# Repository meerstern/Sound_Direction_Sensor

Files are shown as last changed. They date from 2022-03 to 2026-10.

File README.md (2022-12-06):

#  音方位センサ基板
# Sound_Direction_Sensor
This board detects the direction of sound with 4-pdm mems mic using GCC-PHAT algorithm.

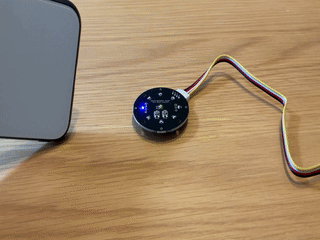
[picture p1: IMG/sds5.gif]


## 概要
  * 音の時間差から計算して8つのLED及びI2C、UARTで結果(角度)を出力する基板です  
  * 4つのPDMデジタルマイクSPH0641LMおよびSTM32F411RCを搭載しています  
  * GCC-PHAT(Generalized Cross-Correlation. PHAse Transform)方式です  
  * 数kHz前後の音をフィルタして音の時間差から方位を検出します  
  * 誤検知を低減するために、音変化（標準偏差）が大きい場合に角度出力します  
  * 音変化（標準偏差）の閾値は基板上の可変抵抗もしくはコマンドから変更できます  
  * 人の声やリズム音等の方位検出に向いています  
  * 手やモノを叩く音等の瞬間的な音の場合、反射等の影響が大きく誤検知しやすくなります  
  
## 仕様
  * 角度分解能は約22.5度～30度程度(音源や環境、処理に依存)
  * 方位LED 8つ搭載
  * 1秒間に約5~6回測定し、結果を出力します  
  * 36kHzサンプリング
  * 電源3.3~5V、UARTもしくはI2C(5V耐圧)
  * I2CはGrove互換コネクタ搭載、UARTは基板上ピンヘッダから接続  
  * UARTボーレート9600bps、データサイズ8bit、パリティ無、ストップ1bitが既定値です  
  * 起動直後にのみ基板上の可変抵抗を読み取り、音変化（標準偏差）の閾値として設定します  
  * I2CもしくはUARTから音変化（標準偏差）閾値を上書き設定できます  
  * リセットや電源再投入で音変化（標準偏差）閾値は消去され、保持されません(可変抵抗値が再度反映)  
  * 電源投入後、自動的に方位検知を開始するため、電源供給のみで方位検知可能です  
  
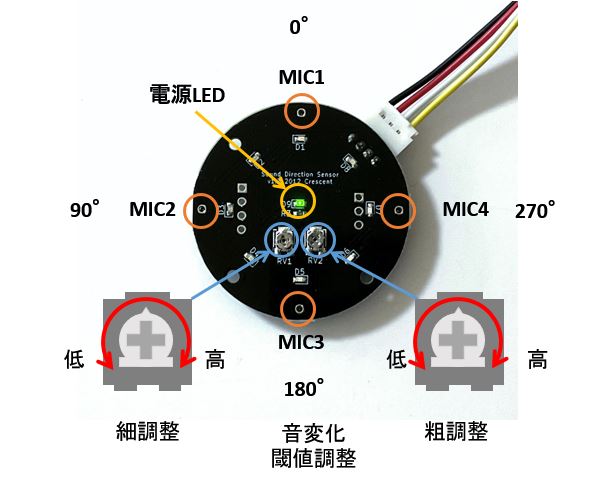
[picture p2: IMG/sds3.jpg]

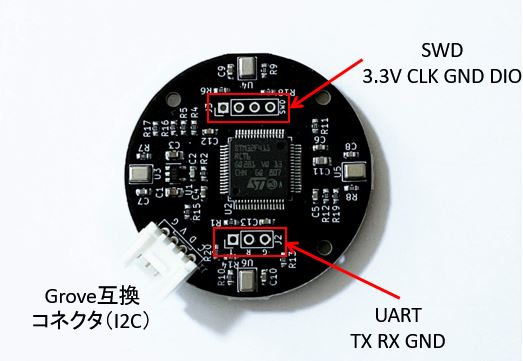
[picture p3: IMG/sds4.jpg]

  
## 外形
  * 40mm円形基板(コネクタ含まず)
  * マイク距離36mm円形
  * M2穴x3 穴間隔横および縦 24.3mm
  
## アプリケーション例
  * 音源の方向を向く小型の首振りロボット  
  * 声でカメラの向きを動かして撮影するカメラステージ
   
## 注意点
  * 厳密な角度検出が必要な用途には向いていません  
  * 音の反射やサンプリングタイミングによって誤検知する場合があります  
  * 騒音環境下、衝撃/振動環境下の用途には向いていません  
  * 5cm程度～1m程度の音の方位の検出を想定しています  
  * 数m以上の遠方からの音の場合、反射等の影響で誤検知の可能性が高くなります  
  * 頻繁に方位LEDが点灯する場合や誤検知が多発する場合は音変化閾値を上げてください  
  * 場合によって起動直後数秒間はソフトフィルタ処理の影響で方位検出が安定しない場合があります  
  * Groveケーブルは同梱されていません 別途ご用意ください   

## 閾値調整目安
  * 音源がない環境下での音変化値Actに対して閾値を1.2~1.5倍程度の値に設定してください  
  * 誤検知が多い場合は環境に応じて閾値を音変化値Actに対してより高く設定してください  
  　例　静かな状態で音変化0.8前後の場合、音変化閾値を1.2程度に設定  
   
## UART通信 
  * 起動直後はファームのバージョンおよびビルド日時、音変化の閾値が出力されます  
  * 1秒間に約5~6回、検出角度Deg、フィルタ前角度DegOrg、音変化値Actが出力されます  
  * 音変化閾値以下は未検出として-1度を出力します  
  * act=XX.XX(Enterキー)で音変換閾値を変更できます  
  * act?(Enterキー)で現状の音変換閾値を確認できます  
  * rst!(Enterキー)でソフトウェアリセットさせることができます 
  * 下記の例では音変換閾値1.0のため、1.0を超えて音変換値1.6の4つ目が206.6度として検出  
    
	Sound Direction Sensor vX.X (ビルド日時)[\r\n]  
	Activity Threshold: 1.0[\r\n]  
	Deg:-1.0,        DegOrg:201.8,   Act:0.69,[\r\n]  
	Deg:-1.0,        DegOrg:0.0,     Act:0.71,[\r\n]  
	Deg:-1.0,        DegOrg:90.0,    Act:0.73,[\r\n]  
	Deg:206.6,       DegOrg:206.6,   Act:1.60,[\r\n]  
	Deg:-1.0,        DegOrg:90.0,    Act:0.73,[\r\n]  

| コマンド名 | コマンド | 引数 | 例 | 
|:---|:---|:---|:---|
| 音変換閾値設定 | act= | 小数設定値 | act=1.2(Enterキー) |
| 音変換閾値確認 | act? | なし | act?(Enterキー) |
| リセット |	rst! | なし | rst!(Enterキー) | 

## I2C通信
　 * I2Cデバイスアドレスは0x60(8bitアドレス)、0x30(7bitアドレス)です  
  * 角度および音変化値は10倍の整数値がレジスタに格納されています  
  * 必要に応じてマスタ側で0.1を乗算し、角度等に変換してください  
  * 書き込み時についても同様に設定したい閾値の10倍の整数値を書き込んでください  
    
  * 読み込み
  
| レジスタ名 | オフセット | 詳細 | 
|:---|:---|:---|
| 角度H(フィルタ後) |0x00 | 角度HighByte | 
| 角度L(フィルタ後) |0x01 | 角度LowByte | 
| 角度H(フィルタ前) |0x02 | 角度HighByte | 
| 角度L(フィルタ前) |0x03 | 角度LowByte | 
| 音変化値H |0x04 | 観測値HighByte | 
| 音変換値L |0x05 | 観測値LowByte | 
| 更新フラグ |0x06 | 値更新0x01 | 
| デバイスID |0x07 | 0x43固定値 | 

  * 書き込み  
  
| レジスタ名 | オフセット | 引数 | 
|:---|:---|:---|
| 音変換閾値H |0x04 | 設定値HighByte | 
| 音変換閾値L |0x05 | 設定値LowByte | 

※オフセット0x04で設定値のHighByteとLowByteの2バイトを一度で書き込んでください  
(スレーブアドレス)+(オフセット)+(設定値2Byte)  

## 販売サイト
  * [スイッチサイエンス][2]

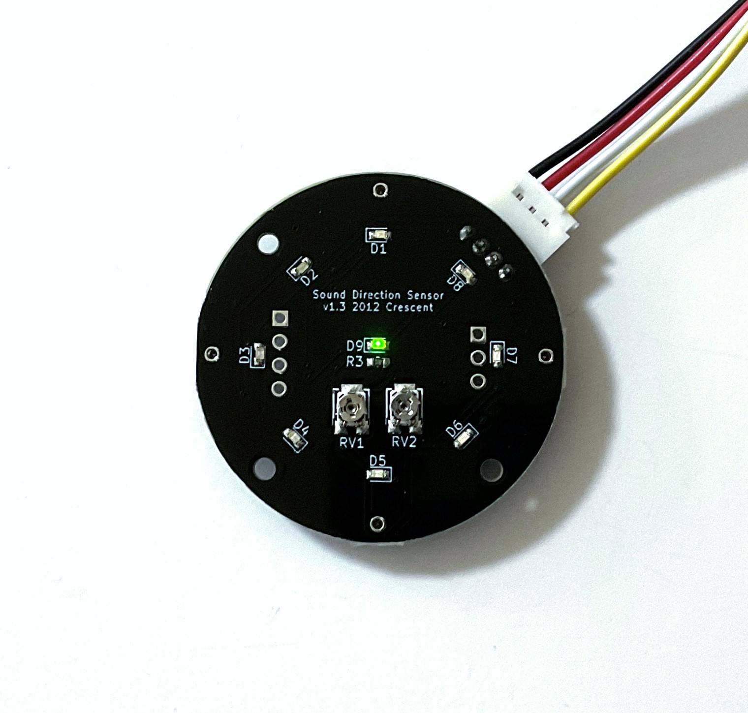
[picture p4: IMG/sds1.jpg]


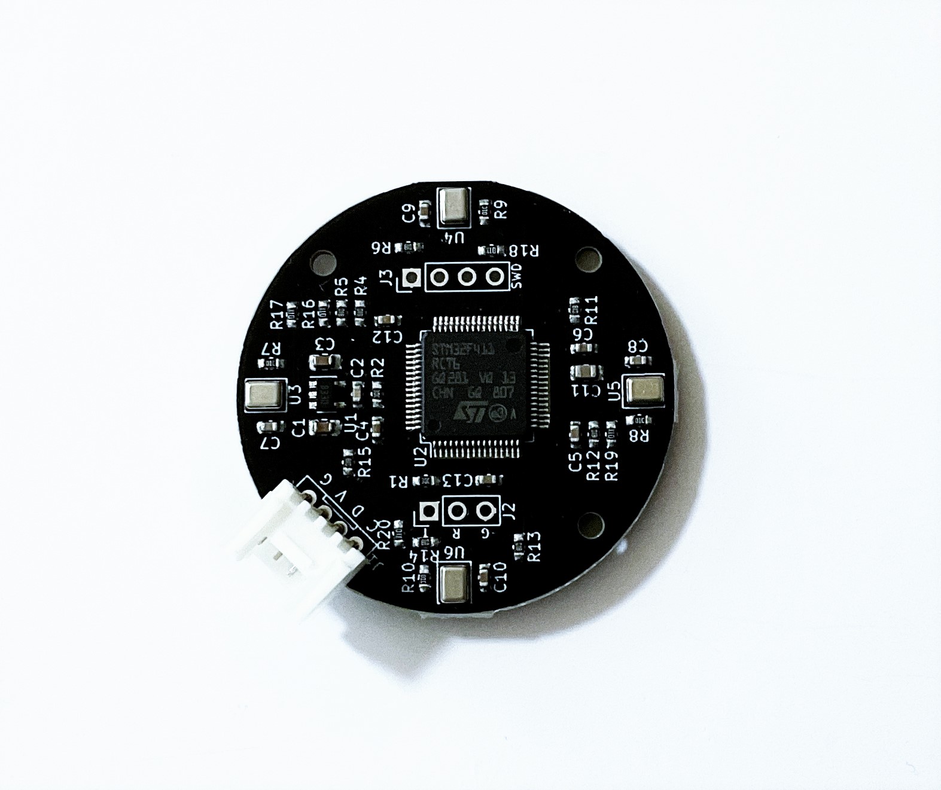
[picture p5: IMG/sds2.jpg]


[2]: https://www.switch-science.com/products/8129

https://youtu.be/5QTcDwFN5Rs

https://youtu.be/rlhwlwNsYnQ

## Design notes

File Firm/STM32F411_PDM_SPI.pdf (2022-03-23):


23/03/2022

## STM32F411_PDM_SPI Project Configuration Report

# 1. Description

## 1.1. Project

Project Name | STM32F411_PDM_SPI
Board Name | NUCLEO-F411RE
Generated with: | STM32CubeMX 6.2.1
Date | 03/23/2022

## 1.2. MCU

MCU Series | STM32F4
MCU Line | STM32F411
MCU name | STM32F411RETx
MCU Package | LQFP64
MCU Pin number | 64

## 1.3. Core(s) information

Core(s) | Arm Cortex-M4

# 2. Pinout Configuration

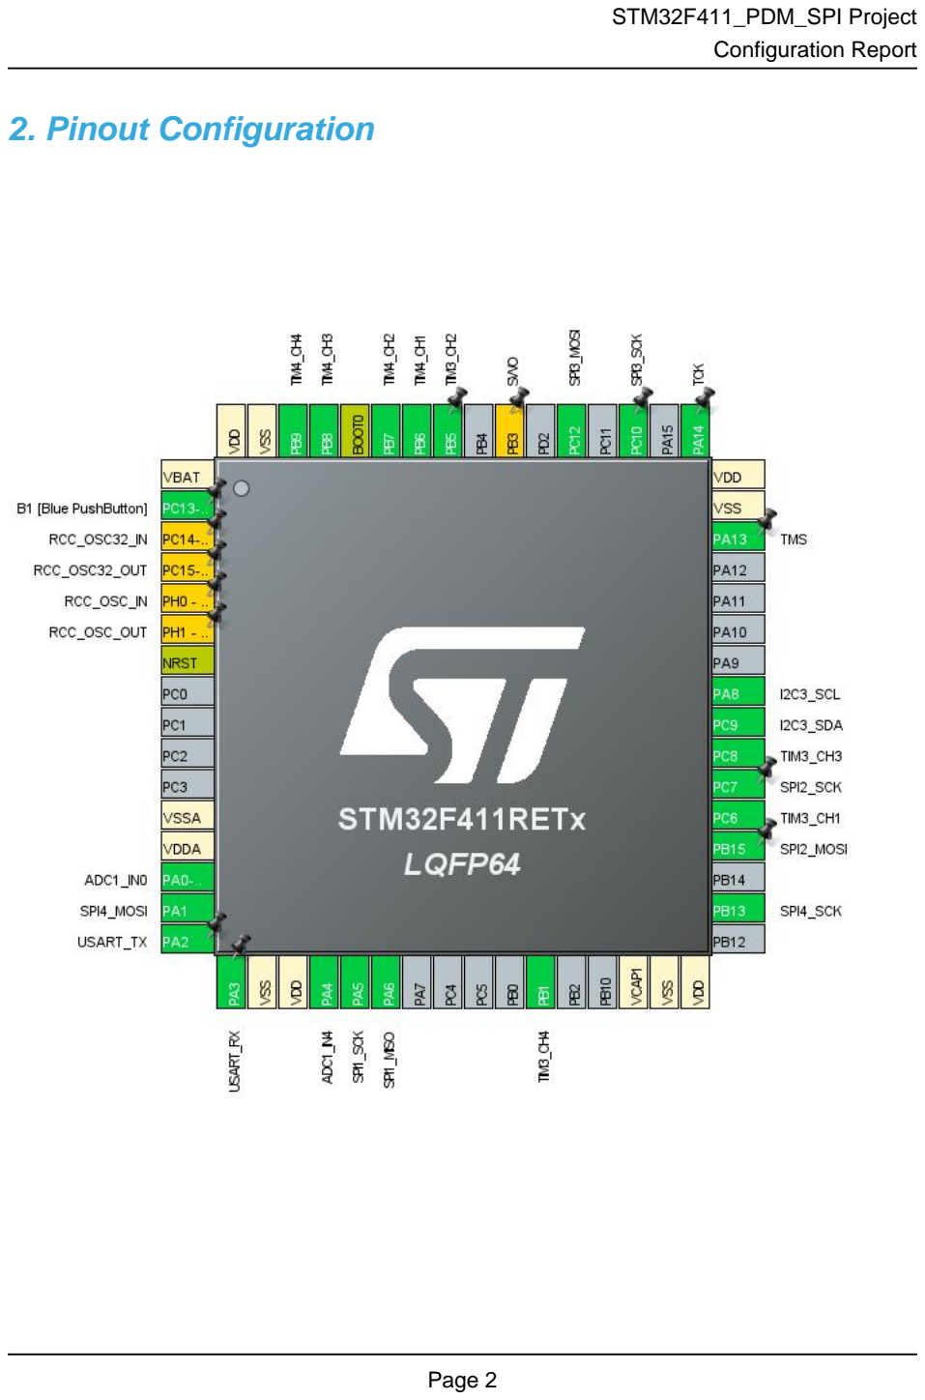
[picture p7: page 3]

# 3. Pins Configuration

Pin Number LQFP64 | Pin Name (function after reset) | Pin Type | Alternate Function(s) | Label
1 | VBAT | Power
2 | PC13-ANTI_TAMP | I/O | GPIO_EXTI13 | B1 [Blue PushButton]
3 | PC14-OSC32_IN * | I/O | RCC_OSC32_IN
4 | PC15-OSC32_OUT * | I/O | RCC_OSC32_OUT
5 | PH0 - OSC_IN * | I/O | RCC_OSC_IN
6 | PH1 - OSC_OUT * | I/O | RCC_OSC_OUT
7 | NRST | Reset
12 | VSSA | Power
13 | VDDA | Power
14 | PA0-WKUP | I/O | ADC1_IN0
15 | PA1 | I/O | SPI4_MOSI
16 | PA2 | I/O | USART2_TX | USART_TX
17 | PA3 | I/O | USART2_RX | USART_RX
18 | VSS | Power
19 | VDD | Power
20 | PA4 | I/O | ADC1_IN4
21 | PA5 | I/O | SPI1_SCK
22 | PA6 | I/O | SPI1_MISO
27 | PB1 | I/O | TIM3_CH4
30 | VCAP1 | Power
31 | VSS | Power
32 | VDD | Power
34 | PB13 | I/O | SPI4_SCK
36 | PB15 | I/O | SPI2_MOSI
37 | PC6 | I/O | TIM3_CH1
38 | PC7 | I/O | SPI2_SCK
39 | PC8 | I/O | TIM3_CH3
40 | PC9 | I/O | I2C3_SDA
41 | PA8 | I/O | I2C3_SCL
46 | PA13 | I/O | SYS_JTMS-SWDIO | TMS
47 | VSS | Power
48 | VDD | Power
49 | PA14 | I/O | SYS_JTCK-SWCLK | TCK
51 | PC10 | I/O | SPI3_SCK
53 | PC12 | I/O | SPI3_MOSI
55 | PB3 * | I/O | SYS_JTDO-SWO | SWO

Pin Number LQFP64 | Pin Name (function after reset) | Pin Type | Alternate Function(s) | Label
57 | PB5 | I/O | TIM3_CH2
58 | PB6 | I/O | TIM4_CH1
59 | PB7 | I/O | TIM4_CH2
60 | BOOT0 | Boot
61 | PB8 | I/O | TIM4_CH3
62 | PB9 | I/O | TIM4_CH4
63 | VSS | Power
64 | VDD | Power

## * The pin is affected with a peripheral function but no peripheral mode is activated

# 4. Clock Tree Configuration

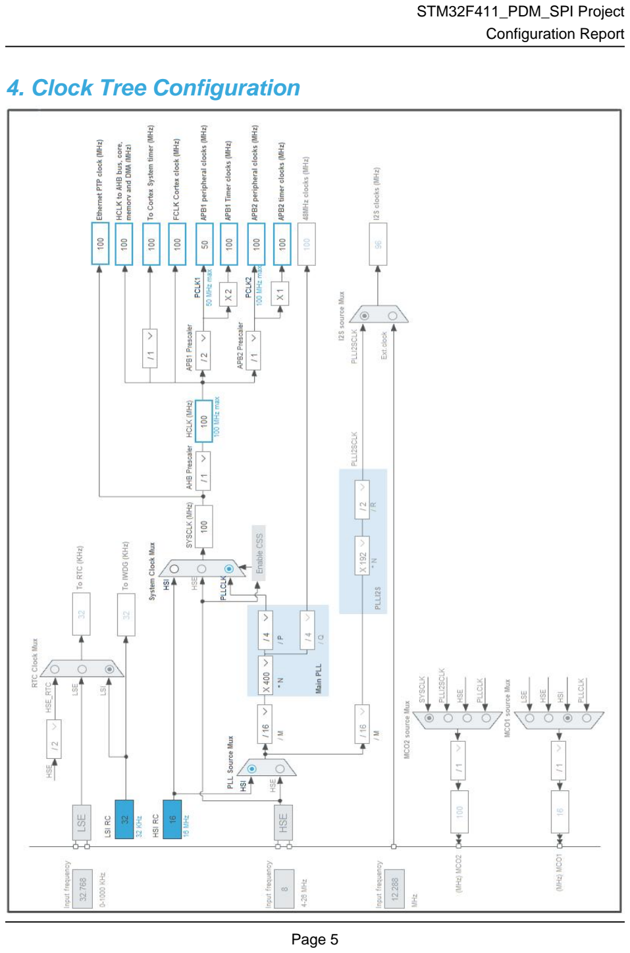
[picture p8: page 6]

# 5. Software Project

## 5.1. Project Settings

Name | Value
Project Name | STM32F411_PDM_SPI
Project Folder | C:\Users\MOND\Desktop\Firm
Toolchain / IDE | SW4STM32
Firmware Package Name and Version | STM32Cube FW_F4 V1.26.1
Application Structure | Basic
Generate Under Root | Yes
Do not generate the main() | No
Minimum Heap Size | 0x200
Minimum Stack Size | 0x400

## 5.2. Code Generation Settings

Name | Value
STM32Cube MCU packages and embedded software | Copy only the necessary library files
Generate peripheral initialization as a pair of '.c/.h' files | No
Backup previously generated files when re-generating | No
Keep User Code when re-generating | Yes
Delete previously generated files when not re-generated | Yes
Set all free pins as analog (to optimize the power consumption) | No
Enable Full Assert | No

## 5.3. Advanced Settings - Generated Function Calls

Rank | Function Name | Peripheral Instance Name
1 | MX_GPIO_Init | GPIO
2 | MX_DMA_Init | DMA
3 | SystemClock_Config | RCC
4 | MX_SPI1_Init | SPI1
5 | MX_USART2_UART_Init | USART2
6 | MX_SPI2_Init | SPI2
7 | MX_SPI3_Init | SPI3
8 | MX_SPI4_Init | SPI4
9 | MX_TIM3_Init | TIM3
10 | MX_TIM4_Init | TIM4
11 | MX_ADC1_Init | ADC1

Rank | Function Name | Peripheral Instance Name
12 | MX_I2C3_Init | I2C3

# 6. Power Consumption Calculator report

## 6.1. Microcontroller Selection

Series | STM32F4
Line | STM32F411
MCU | STM32F411RETx
Datasheet | DS10314_Rev6

## 6.2. Parameter Selection

Temperature | 25
Vdd | 1.7

## 6.3. Battery Selection

Battery | Li-SOCL2(A3400)
Capacity | 3400.0 mAh
Self Discharge | 0.08 %/month
Nominal Voltage | 3.6 V
Max Cont Current | 100.0 mA
Max Pulse Current | 200.0 mA
Cells in series | 1
Cells in parallel | 1

## 6.4. Sequence

Step | Step1 | Step2
Mode | RUN | STOP
Vdd | 1.7 | 1.7
Voltage Source | Battery | Battery
Range | Scale1-High | No Scale
Fetch Type | SRAM | n/a
CPU Frequency | 100 MHz | 0 Hz
Clock Configuration | HSE PLL | Regulator_LPLV Flash-PwrDwn
Clock Source Frequency | 4 MHz | 0 Hz

### Peripherals

Additional Cons. | 0 mA | 0 mA
Average Current | 12.7 mA | 9 µA
Duration | 0.1 ms | 0.9 ms
DMIPS | 125.0 | 0.0
Ta Max | 103.99 | 105
Category | In DS Table | In DS Table

## 6.5. Results

Sequence Time | 1 ms | Average Current | 1.28 mA
Battery Life | 3 months, 19 days, 6 hours | Average DMIPS | 125.0 DMIPS

## 6.6. Chart

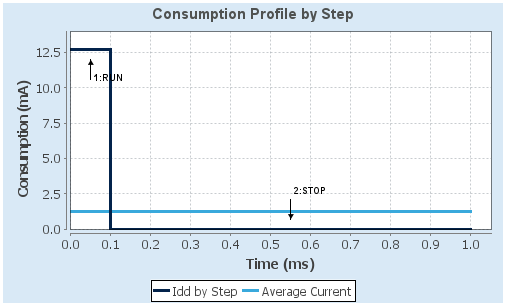
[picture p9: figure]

# 7. Peripherals and Middlewares Configuration

## 7.1. ADC1 mode: IN0 mode: IN4

## 7.1.1. Parameter Settings:

### ADCs_Common_Settings:

Mode | Independent mode

### ADC_Settings:

Clock Prescaler | PCLK2 divided by 4
Resolution | 12 bits (15 ADC Clock cycles)
Data Alignment | Right alignment
Scan Conversion Mode | Disabled
Continuous Conversion Mode | Disabled
Discontinuous Conversion Mode | Disabled
DMA Continuous Requests | Disabled
End Of Conversion Selection | EOC flag at the end of single channel conversion

### ADC_Regular_ConversionMode:

Number Of Conversion | 1
External Trigger Conversion Source | Regular Conversion launched by software
External Trigger Conversion Edge | None
Rank | 1
Channel | Channel 0
Sampling Time | 3 Cycles

### ADC_Injected_ConversionMode:

Number Of Conversions | 0

### WatchDog:

Enable Analog WatchDog Mode | false

## 7.2. I2C3 I2C: I2C

## 7.2.1. Parameter Settings:

### Master Features:

I2C Speed Mode | Standard Mode
I2C Clock Speed (Hz) | 100000

### Slave Features:

Clock No Stretch Mode | Disabled

Primary Address Length selection | 7-bit
Dual Address Acknowledged | Disabled
Primary slave address | 0x60 *
General Call address detection | Disabled

## 7.3. RCC

## 7.3.1. Parameter Settings:

### System Parameters:

VDD voltage (V) | 3.3
Instruction Cache | Enabled
Prefetch Buffer | Enabled
Data Cache | Enabled
Flash Latency(WS) | 3 WS (4 CPU cycle)

### RCC Parameters:

HSI Calibration Value | 16
TIM Prescaler Selection | Disabled
HSE Startup Timout Value (ms) | 100
LSE Startup Timout Value (ms) | 5000

### Power Parameters:

Power Regulator Voltage Scale | Power Regulator Voltage Scale 1

## 7.4. SPI1 Mode: Receive Only Master

## 7.4.1. Parameter Settings:

### Basic Parameters:

Frame Format | Motorola
Data Size | 8 Bits
First Bit | LSB First *

### Clock Parameters:

Prescaler (for Baud Rate) | 128 *
Baud Rate | 781.25 KBits/s *
Clock Polarity (CPOL) | Low
Clock Phase (CPHA) | 1 Edge

### Advanced Parameters:

CRC Calculation | Disabled

NSS Signal Type | Software

## 7.5. SPI2 Mode: Receive Only Slave

## 7.5.1. Parameter Settings:

### Basic Parameters:

Frame Format | Motorola
Data Size | 8 Bits
First Bit | LSB First *

### Clock Parameters:

Clock Polarity (CPOL) | Low
Clock Phase (CPHA) | 1 Edge

### Advanced Parameters:

CRC Calculation | Disabled
NSS Signal Type | Software

## 7.6. SPI3 Mode: Receive Only Slave

## 7.6.1. Parameter Settings:

### Basic Parameters:

Frame Format | Motorola
Data Size | 8 Bits
First Bit | LSB First *

### Clock Parameters:

Clock Polarity (CPOL) | Low
Clock Phase (CPHA) | 1 Edge

### Advanced Parameters:

CRC Calculation | Disabled
NSS Signal Type | Software

## 7.7. SPI4 Mode: Receive Only Slave

## 7.7.1. Parameter Settings:

### Basic Parameters:

Frame Format | Motorola
Data Size | 8 Bits
First Bit | LSB First *

### Clock Parameters:

Clock Polarity (CPOL) | Low
Clock Phase (CPHA) | 1 Edge

### Advanced Parameters:

CRC Calculation | Disabled
NSS Signal Type | Software

## 7.8. SYS Debug: Serial Wire Timebase Source: SysTick

## 7.9. TIM3 Channel1: PWM Generation CH1 Channel2: PWM Generation CH2 Channel3: PWM Generation CH3 Channel4: PWM Generation CH4

## 7.9.1. Parameter Settings:

### Counter Settings:

Prescaler (PSC - 16 bits value) | 2 *
Counter Mode | Up
Counter Period (AutoReload Register - 16 bits value ) | 1024 *
Internal Clock Division (CKD) | No Division
auto-reload preload | Disable

### Trigger Output (TRGO) Parameters:

Master/Slave Mode (MSM bit) | Disable (Trigger input effect not delayed)
Trigger Event Selection | Reset (UG bit from TIMx_EGR)

### PWM Generation Channel 1:

Mode | PWM mode 1
Pulse (16 bits value) | 0
Output compare preload | Enable

Fast Mode | Disable
CH Polarity | High

### PWM Generation Channel 2:

Mode | PWM mode 1
Pulse (16 bits value) | 0
Output compare preload | Enable
Fast Mode | Disable
CH Polarity | High

### PWM Generation Channel 3:

Mode | PWM mode 1
Pulse (16 bits value) | 0
Output compare preload | Enable
Fast Mode | Disable
CH Polarity | High

### PWM Generation Channel 4:

Mode | PWM mode 1
Pulse (16 bits value) | 0
Output compare preload | Enable
Fast Mode | Disable
CH Polarity | High

## 7.10. TIM4 Channel1: PWM Generation CH1 Channel2: PWM Generation CH2 Channel3: PWM Generation CH3 Channel4: PWM Generation CH4

## 7.10.1. Parameter Settings:

### Counter Settings:

Prescaler (PSC - 16 bits value) | 2 *
Counter Mode | Up
Counter Period (AutoReload Register - 16 bits value ) | 1024 *
Internal Clock Division (CKD) | No Division
auto-reload preload | Disable

### Trigger Output (TRGO) Parameters:

Master/Slave Mode (MSM bit) | Disable (Trigger input effect not delayed)
Trigger Event Selection | Reset (UG bit from TIMx_EGR)

### PWM Generation Channel 1:

Mode | PWM mode 1

Pulse (16 bits value) | 0
Output compare preload | Enable
Fast Mode | Disable
CH Polarity | High

### PWM Generation Channel 2:

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

### PWM Generation Channel 3:

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

### PWM Generation Channel 4:

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

## 7.11. USART2 Mode: Asynchronous

## 7.11.1. Parameter Settings:

### Basic Parameters:

Baud Rate | 9600 *
Word Length | 8 Bits (including Parity)
Parity | None
Stop Bits | 1

### Advanced Parameters:

Data Direction | Receive and Transmit
Over Sampling | 16 Samples

### * User modified value

# 8. System Configuration

## 8.1. GPIO configuration

IP | Pin | Signal | GPIO mode | GPIO pull/up pull down

## Max Speed

## User Label

ADC1 | PA0-WKUP | ADC1_IN0 | Analog mode | No pull-up and no pull-down | n/a
| PA4 | ADC1_IN4 | Analog mode | No pull-up and no pull-down | n/a
I2C3 | PC9 | I2C3_SDA | Alternate Function Open Drain | Pull-up | Very High
*
| PA8 | I2C3_SCL | Alternate Function Open Drain | Pull-up | Very High
*
SPI1 | PA5 | SPI1_SCK | Alternate Function Push Pull | No pull-up and no pull-down | Very High
*
| PA6 | SPI1_MISO | Alternate Function Push Pull | No pull-up and no pull-down | Very High
*
SPI2 | PB15 | SPI2_MOSI | Alternate Function Push Pull | No pull-up and no pull-down | Very High
*
| PC7 | SPI2_SCK | Alternate Function Push Pull | No pull-up and no pull-down | Very High
*
SPI3 | PC10 | SPI3_SCK | Alternate Function Push Pull | No pull-up and no pull-down | Very High
*
| PC12 | SPI3_MOSI | Alternate Function Push Pull | No pull-up and no pull-down | Very High
*
SPI4 | PA1 | SPI4_MOSI | Alternate Function Push Pull | No pull-up and no pull-down | Very High
*
| PB13 | SPI4_SCK | Alternate Function Push Pull | No pull-up and no pull-down | Very High
*
SYS | PA13 | SYS_JTMS- SWDIO
n/a | n/a | n/a | TMS
| PA14 | SYS_JTCK- SWCLK
n/a | n/a | n/a | TCK
TIM3 | PB1 | TIM3_CH4 | Alternate Function Push Pull | No pull-up and no pull-down | Low
| PC6 | TIM3_CH1 | Alternate Function Push Pull | No pull-up and no pull-down | Low
| PC8 | TIM3_CH3 | Alternate Function Push Pull | No pull-up and no pull-down | Low
| PB5 | TIM3_CH2 | Alternate Function Push Pull | No pull-up and no pull-down | Low
TIM4 | PB6 | TIM4_CH1 | Alternate Function Push Pull | No pull-up and no pull-down | Low
| PB7 | TIM4_CH2 | Alternate Function Push Pull | No pull-up and no pull-down | Low
| PB8 | TIM4_CH3 | Alternate Function Push Pull | No pull-up and no pull-down | Low
| PB9 | TIM4_CH4 | Alternate Function Push Pull | No pull-up and no pull-down | Low
USART2 | PA2 | USART2_TX | Alternate Function Push Pull | No pull-up and no pull-down | USART_TX

IP | Pin | Signal | GPIO mode | GPIO pull/up pull down | Max Speed | User Label
| | | | | Very High *
| PA3 | USART2_RX | Alternate Function Push Pull | No pull-up and no pull-down | Very High * | USART_RX
Single Mapped Signals | PC14-OSC32_IN | RCC_OSC32_IN | n/a | n/a | n/a
| PC15-OSC32_OU T | RCC_OSC32_O UT | n/a | n/a | n/a
| PH0 -OSC_IN | RCC_OSC_IN | n/a | n/a | n/a
| PH1 -OSC_OUT | RCC_OSC_OUT | n/a | n/a | n/a
| PB3 | SYS_JTDO-SWO | n/a | n/a | n/a | SWO
GPIO | PC13-ANTI_TAMP | GPIO_EXTI13 | External Interrupt Mode with Falling edge trigger detection | No pull-up and no pull-down | n/a | B1 [Blue PushButton]

## 8.2. DMA configuration

DMA request | Stream | Direction | Priority
SPI1_RX | DMA2_Stream0 | Peripheral To Memory | Very High *
SPI2_RX | DMA1_Stream3 | Peripheral To Memory | High *
SPI3_RX | DMA1_Stream0 | Peripheral To Memory | High *
SPI4_RX | DMA2_Stream3 | Peripheral To Memory | High *
I2C3_RX | DMA1_Stream1 | Peripheral To Memory | Low
I2C3_TX | DMA1_Stream4 | Memory To Peripheral | Low
USART2_RX | DMA1_Stream5 | Peripheral To Memory | Low
USART2_TX | DMA1_Stream6 | Memory To Peripheral | Low

## SPI1_RX: DMA2_Stream0 DMA request Settings:

Mode: | Circular *
Use fifo: | Disable
Peripheral Increment: | Disable
Memory Increment: | Enable *
Peripheral Data Width: | Byte
Memory Data Width: | Byte

## SPI2_RX: DMA1_Stream3 DMA request Settings:

Mode: | Circular *
Use fifo: | Disable
Peripheral Increment: | Disable
Memory Increment: | Enable *
Peripheral Data Width: | Byte
Memory Data Width: | Byte

## SPI3_RX: DMA1_Stream0 DMA request Settings:

Mode: | Circular *
Use fifo: | Disable
Peripheral Increment: | Disable
Memory Increment: | Enable *
Peripheral Data Width: | Byte
Memory Data Width: | Byte

## SPI4_RX: DMA2_Stream3 DMA request Settings:

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

## I2C3_RX: DMA1_Stream1 DMA request Settings:

Mode: | Normal
Use fifo: | Disable
Peripheral Increment: | Disable
Memory Increment: | Enable *
Peripheral Data Width: | Byte
Memory Data Width: | Byte

## I2C3_TX: DMA1_Stream4 DMA request Settings:

Mode: | Normal
Use fifo: | Disable
Peripheral Increment: | Disable
Memory Increment: | Enable *
Peripheral Data Width: | Byte
Memory Data Width: | Byte

## USART2_RX: DMA1_Stream5 DMA request Settings:

Mode: | Normal
Use fifo: | Disable
Peripheral Increment: | Disable
Memory Increment: | Enable *
Peripheral Data Width: | Byte
Memory Data Width: | Byte

## USART2_TX: DMA1_Stream6 DMA request Settings:

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

## 8.3. NVIC configuration

## 8.3.1. NVIC

Interrupt Table | Enable | Preenmption Priority | SubPriority
Non maskable interrupt | true | 0 | 0
Hard fault interrupt | true | 0 | 0
Memory management fault | true | 0 | 0
Pre-fetch fault, memory access fault | true | 0 | 0
Undefined instruction or illegal state | true | 0 | 0
System service call via SWI instruction | true | 0 | 0
Debug monitor | true | 0 | 0
Pendable request for system service | true | 0 | 0
System tick timer | true | 0 | 0
DMA1 stream0 global interrupt | true | 0 | 0
DMA1 stream1 global interrupt | true | 0 | 0
DMA1 stream3 global interrupt | true | 0 | 0
DMA1 stream4 global interrupt | true | 0 | 0
DMA1 stream5 global interrupt | true | 0 | 0
DMA1 stream6 global interrupt | true | 0 | 0
TIM3 global interrupt | true | 0 | 0
TIM4 global interrupt | true | 0 | 0
SPI1 global interrupt | true | 0 | 0
SPI2 global interrupt | true | 0 | 0
USART2 global interrupt | true | 0 | 0
SPI3 global interrupt | true | 0 | 0
DMA2 stream0 global interrupt | true | 0 | 0
DMA2 stream3 global interrupt | true | 0 | 0
I2C3 event interrupt | true | 0 | 0
I2C3 error interrupt | true | 0 | 0
SPI4 global interrupt | true | 0 | 0
PVD interrupt through EXTI line 16 | | unused
Flash global interrupt | | unused
RCC global interrupt | | unused
ADC1 global interrupt | | unused
EXTI line[15:10] interrupts | | unused
FPU global interrupt | | unused

## 8.3.2. NVIC Code generation

## Enabled interrupt Table Select for init sequence ordering

| | Generate IRQ
| | handler | Call HAL handler
Non maskable interrupt | false | true | false

Enabled interrupt Table | Select for init sequence ordering | Generate IRQ handler | Call HAL handler
Hard fault interrupt | false | true | false
Memory management fault | false | true | false
Pre-fetch fault, memory access fault | false | true | false
Undefined instruction or illegal state | false | true | false
System service call via SWI instruction | false | true | false
Debug monitor | false | true | false
Pendable request for system service | false | true | false
System tick timer | false | true | true
DMA1 stream0 global interrupt | false | true | true
DMA1 stream1 global interrupt | false | true | true
DMA1 stream3 global interrupt | false | true | true
DMA1 stream4 global interrupt | false | true | true
DMA1 stream5 global interrupt | false | true | true
DMA1 stream6 global interrupt | false | true | true
TIM3 global interrupt | false | true | true
TIM4 global interrupt | false | true | true
SPI1 global interrupt | false | true | true
SPI2 global interrupt | false | true | true
USART2 global interrupt | false | true | true
SPI3 global interrupt | false | true | true
DMA2 stream0 global interrupt | false | true | true
DMA2 stream3 global interrupt | false | true | true
I2C3 event interrupt | false | true | true
I2C3 error interrupt | false | true | true
SPI4 global interrupt | false | true | true

### * User modified value

# 9. System Views

## 9.1. Category view 9.1.1. Current

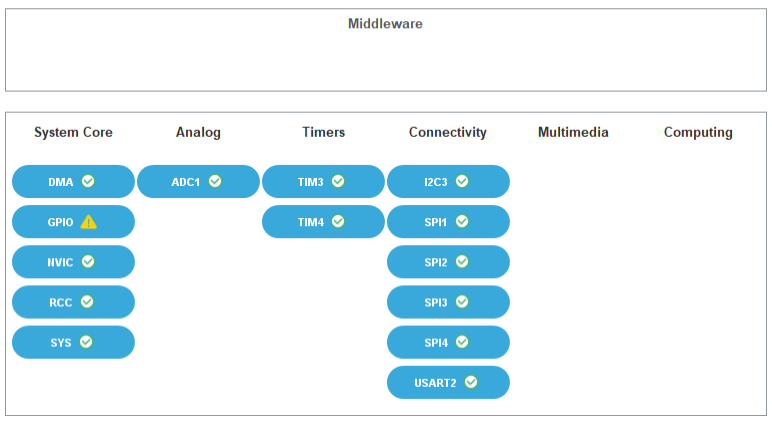
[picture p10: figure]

# 10. Docs & Resources

Type | Link
Datasheet | http://www.st.com/resource/en/datasheet/DM00115249.pdf
Reference manual | http://www.st.com/resource/en/reference_manual/DM00119316.pdf
Programming manual | http://www.st.com/resource/en/programming_manual/DM00046982.pdf
Errata sheet | http://www.st.com/resource/en/errata_sheet/DM00137034.pdf
Application note | http://www.st.com/resource/en/application_note/CD00167594.pdf
Application note | http://www.st.com/resource/en/application_note/CD00211314.pdf
Application note | http://www.st.com/resource/en/application_note/CD00249778.pdf
Application note | http://www.st.com/resource/en/application_note/CD00259245.pdf
Application note | http://www.st.com/resource/en/application_note/CD00264321.pdf
Application note | http://www.st.com/resource/en/application_note/CD00264342.pdf
Application note | http://www.st.com/resource/en/application_note/CD00264379.pdf
Application note | http://www.st.com/resource/en/application_note/DM00024853.pdf
Application note | http://www.st.com/resource/en/application_note/DM00040802.pdf
Application note | http://www.st.com/resource/en/application_note/DM00040808.pdf
Application note | http://www.st.com/resource/en/application_note/DM00042534.pdf
Application note | http://www.st.com/resource/en/application_note/DM00046011.pdf
Application note | http://www.st.com/resource/en/application_note/DM00072315.pdf
Application note | http://www.st.com/resource/en/application_note/DM00073742.pdf
Application note | http://www.st.com/resource/en/application_note/DM00073853.pdf
Application note | http://www.st.com/resource/en/application_note/DM00080497.pdf
Application note | http://www.st.com/resource/en/application_note/DM00081379.pdf
Application note | http://www.st.com/resource/en/application_note/DM00115714.pdf
Application note | http://www.st.com/resource/en/application_note/DM00129215.pdf
Application note | http://www.st.com/resource/en/application_note/DM00156364.pdf
Application note | http://www.st.com/resource/en/application_note/DM00160482.pdf

Application note | http://www.st.com/resource/en/application_note/DM00144612.pdf
Application note | http://www.st.com/resource/en/application_note/DM00213525.pdf
Application note | http://www.st.com/resource/en/application_note/DM00220769.pdf
Application note | http://www.st.com/resource/en/application_note/DM00257177.pdf
Application note | http://www.st.com/resource/en/application_note/DM00272912.pdf
Application note | http://www.st.com/resource/en/application_note/DM00226326.pdf
Application note | http://www.st.com/resource/en/application_note/DM00236305.pdf
Application note | http://www.st.com/resource/en/application_note/DM00281138.pdf
Application note | http://www.st.com/resource/en/application_note/DM00296349.pdf
Application note | http://www.st.com/resource/en/application_note/DM00325582.pdf
Application note | http://www.st.com/resource/en/application_note/DM00327191.pdf
Application note | http://www.st.com/resource/en/application_note/DM00354244.pdf
Application note | http://www.st.com/resource/en/application_note/DM00315319.pdf
Application note | http://www.st.com/resource/en/application_note/DM00380469.pdf
Application note | http://www.st.com/resource/en/application_note/DM00395696.pdf
Application note | http://www.st.com/resource/en/application_note/DM00431633.pdf
Application note | http://www.st.com/resource/en/application_note/DM00493651.pdf
Application note | http://www.st.com/resource/en/application_note/DM00536349.pdf
Application note | http://www.st.com/resource/en/application_note/DM00725181.pdf

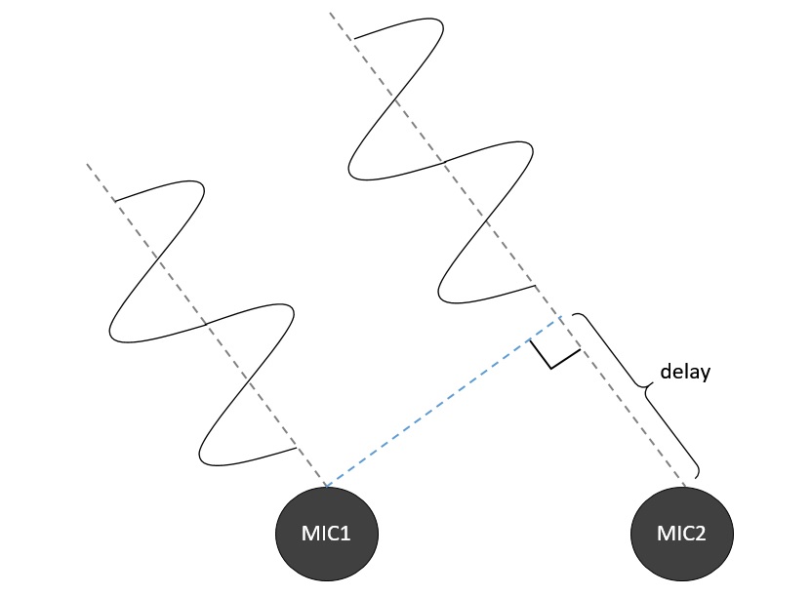
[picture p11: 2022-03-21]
IMG/sds0.jpg

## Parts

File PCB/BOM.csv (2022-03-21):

Elecrow PN | Parts | Value | Package | QTY | Digikey/Mouser/Manufacturer Part | Remark/ Link
 | RV2,RV1 | R_POT | rcl-RTRIMCVR42A | 2 | 652-TC33X-2-103E
 | U2 | STM32F411RETx | LQFP-64_10x10mm_P0.5mm | 1 | STM32F411RCT6
C14663 | C13,C12,C10,C9,C8,C7,C6,C5,C4 | 0.1u | C_0603_1608Metric | 9
2014547A | C11 | 4.7u | C_0805_2012Metric | 1
 | U6,U5,U4,U3 | SPH0641L | SPH0641L | 4 | 721-SPH0641LM4H1
 | U1 | LD3985M33R_SOT23 | SOT-23-5 | 1 | 511-LD3985M33R
C21190 | R15,R14,R13,R12,R11,R6,R5,R4,R3 | 1k | R_0603_1608Metric | 9
C25804 | R10,R9,R8,R7 | 10k | R_0603_1608Metric | 4
C4184 | R2,R1 | 20k | R_0603_1608Metric | 2
 | J1 | GROVE | GROVE | 1 | 713-110990037
4040806A | D8,D7,D6,D5,D4,D3,D2,D1 | LED | D_0603_1608Metric | 8
4040706A | D9 | LED | D_0603_1608Metric | 1
2014210A | C3,C1 | 10u | C_0805_2012Metric | 2
C57112 | C2 | 0.01u | C_0603_1608Metric | 1
C22859 | R16,R17,R18,R19,R20 | 10 | R_0603_1608Metric | 5

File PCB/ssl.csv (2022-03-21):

ID | 参照記号 | パッケージ | 数 | 名称 | Supplier and ref
1 | RV2,RV1 | rcl-RTRIMCVR42A | 2 | R_POT
2 | U2 | LQFP-64_10x10mm_P0.5mm | 1 | STM32F411RETx
3 | C13,C12,C10,C9,C8,C7,C6,C5,C4 | C_0603_1608Metric | 9 | 0.1u
4 | C11 | C_0805_2012Metric | 1 | 4.7u
5 | REF2,REF1,REF3 | MountingHole_2.2mm_M2 | 3 | MountingHole_2.2mm_M2
6 | U6,U5,U4,U3 | SPH0641LU4H | 4 | SPH0641LU4H
7 | U1 | SOT-23-5 | 1 | LD3985M33R_SOT23
8 | R15,R14,R13,R12,R11,R6,R5,R4,R3 | R_0603_1608Metric | 9 | 1k
9 | R10,R9,R8,R7 | R_0603_1608Metric | 4 | 10k
10 | R2,R1 | R_0603_1608Metric | 2 | 20k
11 | J3 | PinHeader_1x04_P2.54mm_Vertical | 1 | SWD
12 | J2 | PinHeader_1x03_P2.54mm_Vertical | 1 | UART
13 | J1 | GROVE | 1 | GROVE
14 | D8,D7,D6,D5,D4,D3,D2,D1,D9 | D_0603_1608Metric | 9 | LED
15 | C3,C1 | C_0805_2012Metric | 2 | 2.2u
16 | C2 | C_0603_1608Metric | 1 | 0.01u
17 | R16,R17,R18,R19,R20 | R_0603_1608Metric | 5 | 10

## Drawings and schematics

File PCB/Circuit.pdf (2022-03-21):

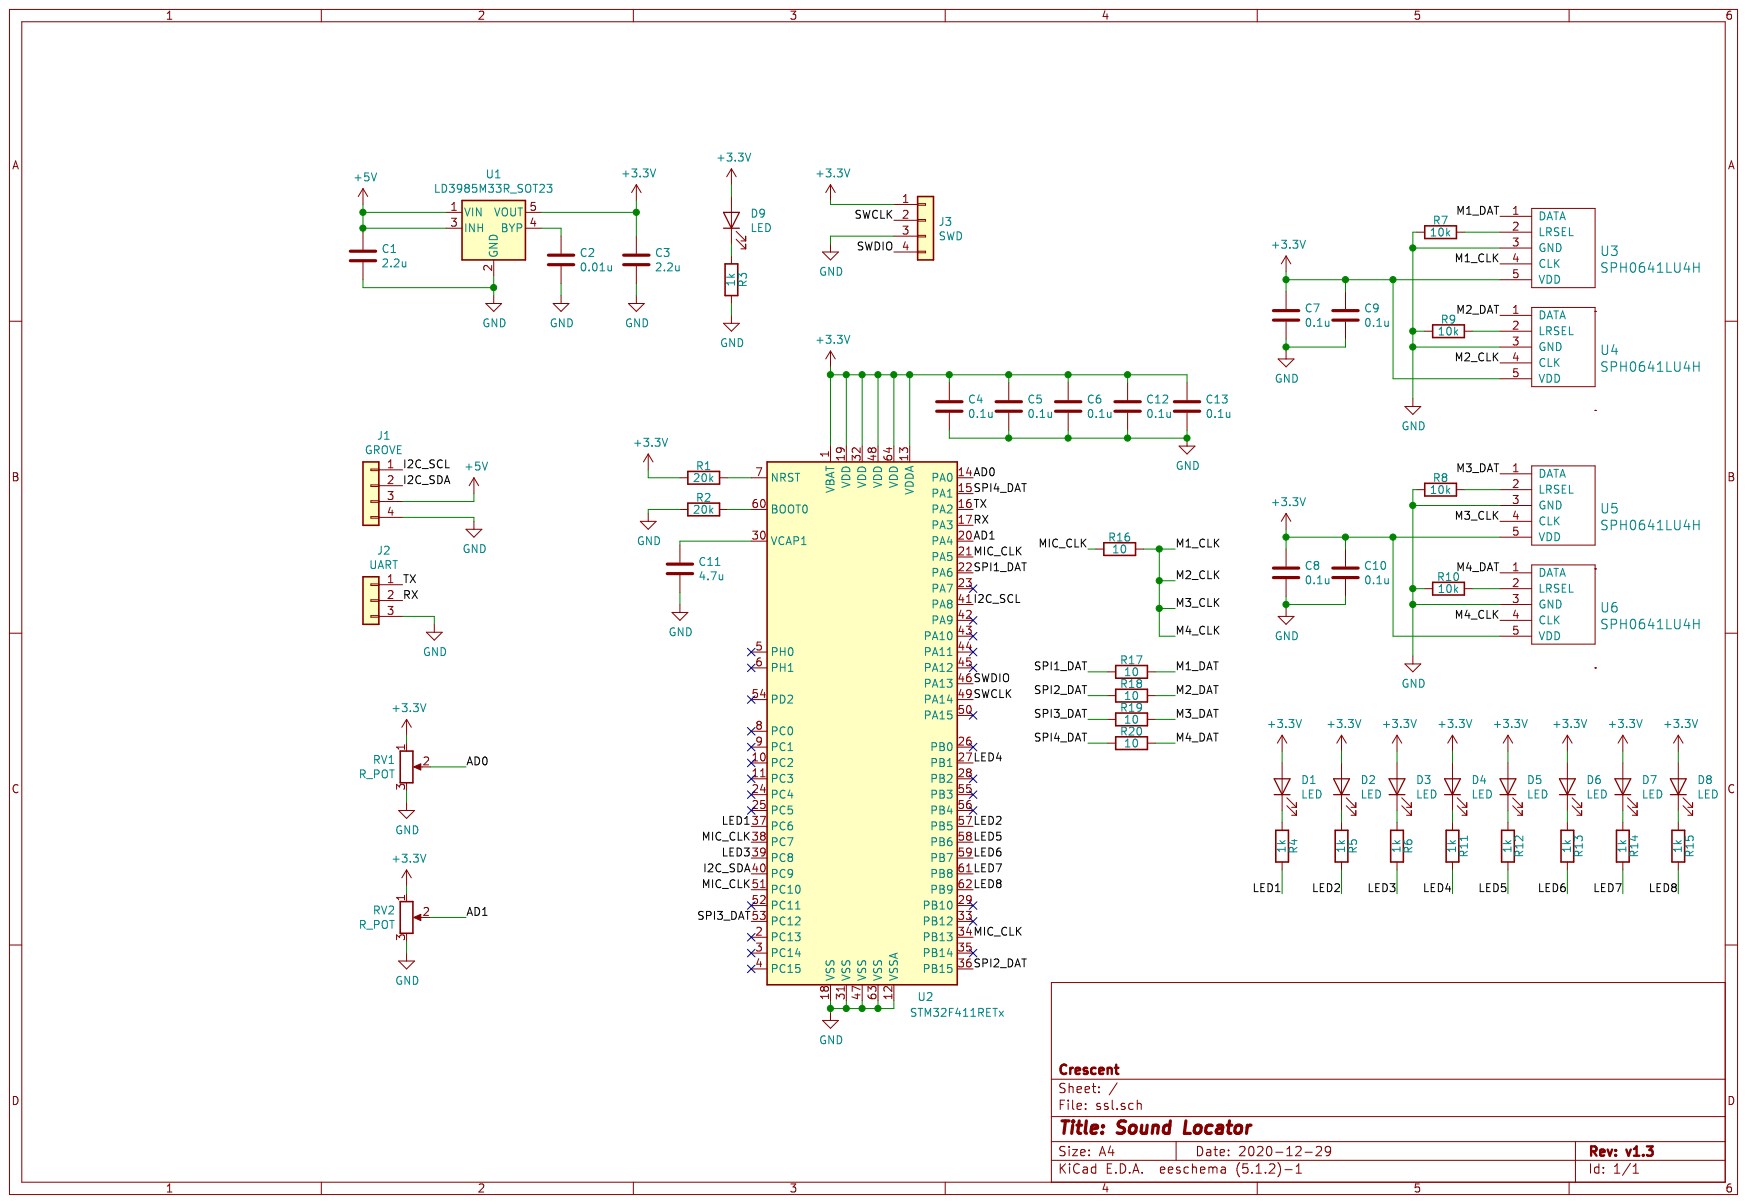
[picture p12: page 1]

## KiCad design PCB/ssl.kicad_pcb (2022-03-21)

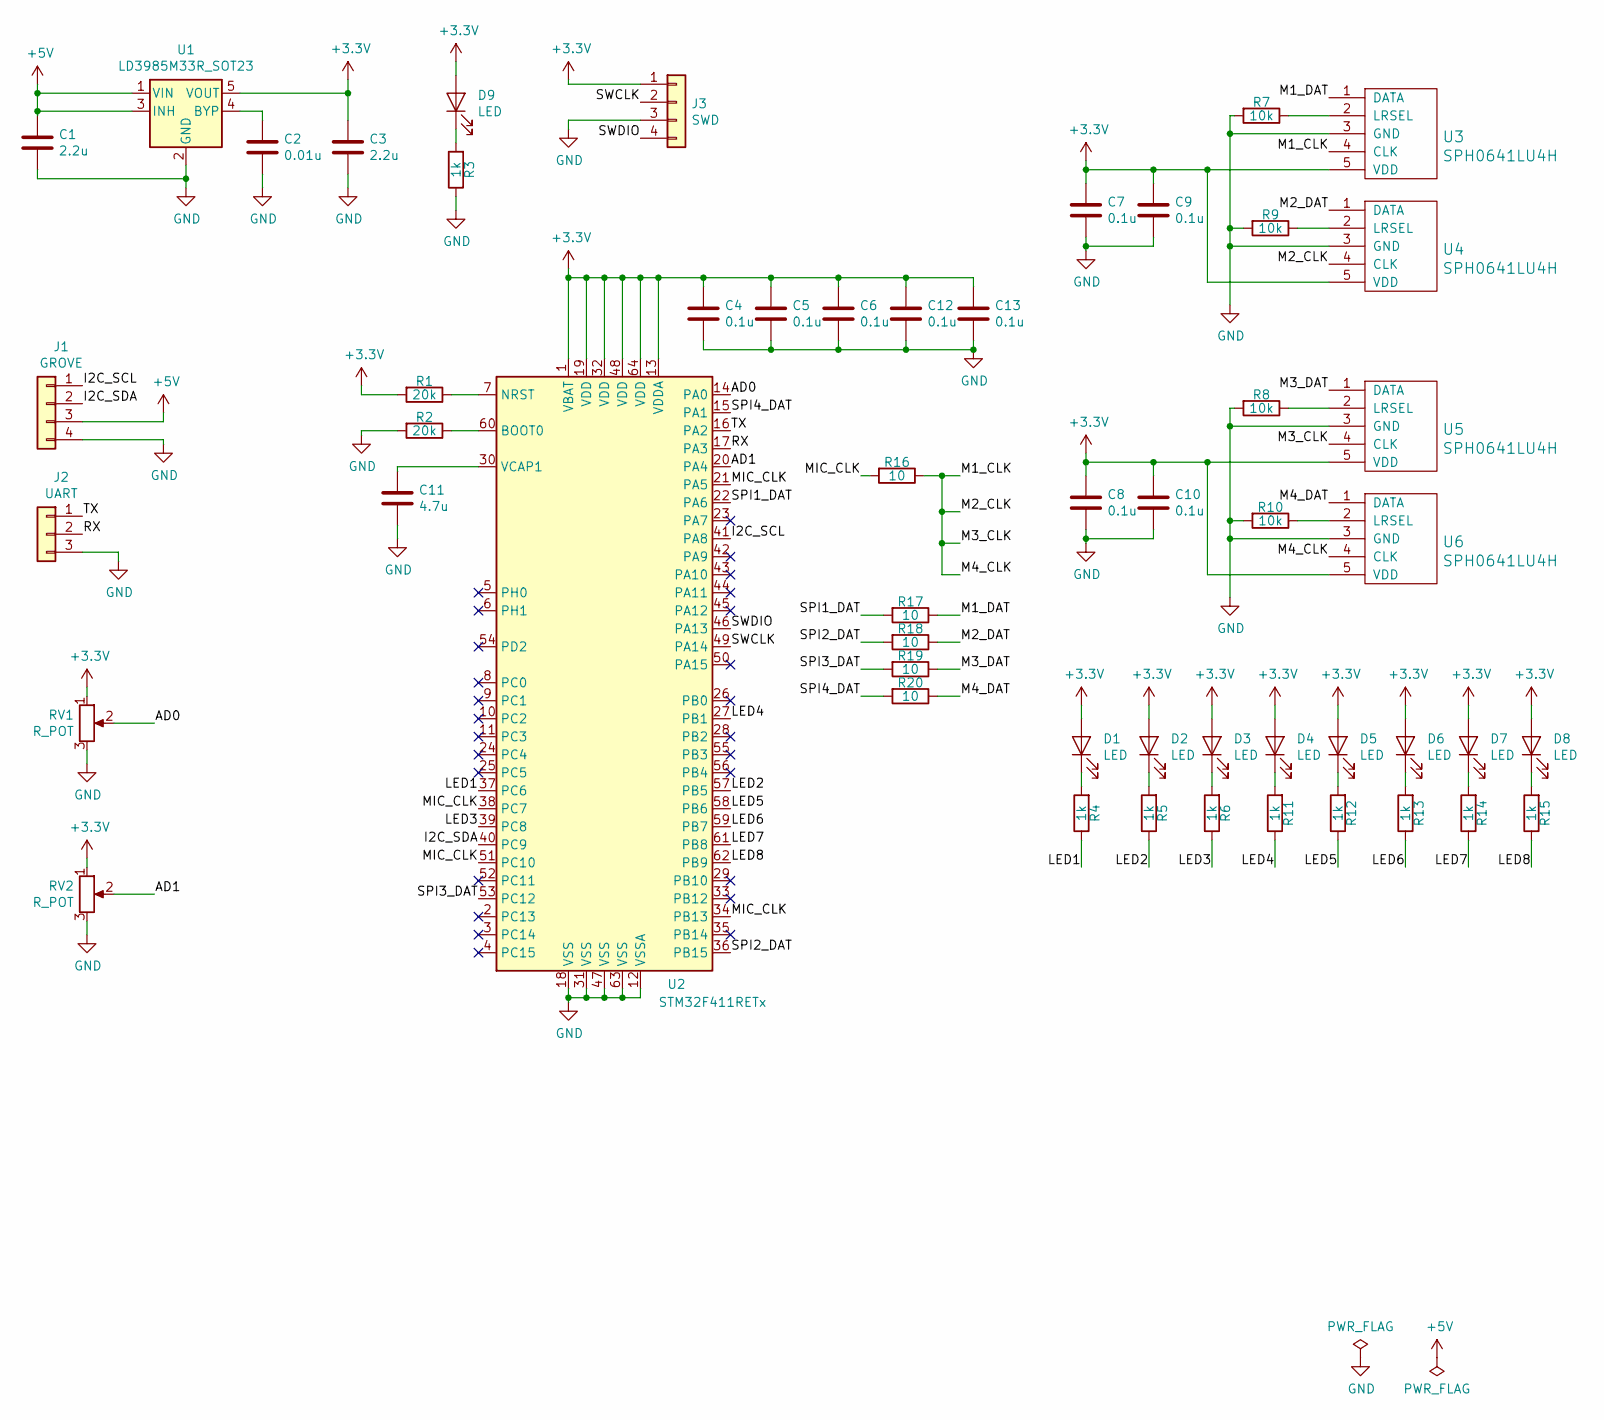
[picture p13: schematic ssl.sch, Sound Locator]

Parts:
C1, C3: 2.2u; C_0805_2012Metric
C2: 0.01u; C_0603_1608Metric
C4, C5, C6, C7, C8, C9, C10, C12, C13: 0.1u; C_0603_1608Metric
C11: 4.7u; C_0805_2012Metric
D1, D2, D3, D4, D5, D6, D7, D8, D9: LED; D_0603_1608Metric
J1: GROVE
J2: UART; PinHeader_1x03_P2.54mm_Vertical
J3: SWD; PinHeader_1x04_P2.54mm_Vertical
R1, R2: 20k; R_0603_1608Metric
R3, R4, R5, R6, R11, R12, R13, R14, R15: 1k; R_0603_1608Metric
R7, R8, R9, R10: 10k; R_0603_1608Metric
R16, R17, R18, R19, R20: 10; R_0603_1608Metric
RV1, RV2: R_POT; rcl-RTRIMCVR42A
U1: LD3985M33R_SOT23; SOT-23-5
U2: STM32F411RETx; LQFP-64_10x10mm_P0.5mm
U3, U4, U5, U6: SPH0641LU4H

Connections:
+3V3: C3.1, C4.1, C5.1, C6.1, C7.1, C8.1, C9.1, C10.1, C12.1, C13.1, D1.2 (A), D2.2 (A), D3.2 (A), D4.2 (A), D5.2 (A), D6.2 (A), D7.2 (A), D8.2 (A), D9.2 (A), J3.1, R1.2, RV1.1, RV2.1, U1.5 (VOUT), U2.1 (VBAT), U2.13 (VDDA), U2.19 (VDD), U2.32 (VDD), U2.48 (VDD), U2.64 (VDD), U3.5 (VDD), U4.5 (VDD), U5.5 (VDD), U6.5 (VDD)
+5V: C1.1, J1.3, U1.1 (VIN), U1.3 (INH)
/AD0: RV1.2, U2.14 (PA0)
/AD1: RV2.2, U2.20 (PA4)
/I2C_SCL: J1.1, U2.41 (PA8)
/I2C_SDA: J1.2, U2.40 (PC9)
/LED1: R4.1, U2.37 (PC6)
/LED2: R5.1, U2.57 (PB5)
/LED3: R6.1, U2.39 (PC8)
/LED4: R11.1, U2.27 (PB1)
/LED5: R12.1, U2.58 (PB6)
/LED6: R13.1, U2.59 (PB7)
/LED7: R14.1, U2.61 (PB8)
/LED8: R15.1, U2.62 (PB9)
/M1_CLK: R16.1, U3.4 (CLK), U4.4 (CLK), U5.4 (CLK), U6.4 (CLK)
/M1_DAT: R17.1, U3.1 (DATA)
/M2_DAT: R18.1, U4.1 (DATA)
/M3_DAT: R19.1, U5.1 (DATA)
/M4_DAT: R20.1, U6.1 (DATA)
/MIC_CLK: R16.2, U2.21 (PA5), U2.34 (PB13), U2.38 (PC7), U2.51 (PC10)
/RX: J2.2, U2.17 (PA3)
/SPI1_DAT: R17.2, U2.22 (PA6)
/SPI2_DAT: R18.2, U2.36 (PB15)
/SPI3_DAT: R19.2, U2.53 (PC12)
/SPI4_DAT: R20.2, U2.15 (PA1)
/SWCLK: J3.2, U2.49 (PA14)
/SWDIO: J3.4, U2.46 (PA13)
/TX: J2.1, U2.16 (PA2)
GND: C1.2, C2.2, C3.2, C4.2, C5.2, C6.2, C7.2, C8.2, C9.2, C10.2, C11.2, C12.2, C13.2, J1.4, J2.3, J3.3, R2.2, R3.1, R7.2, R8.2, R9.2, R10.2, RV1.3, RV2.3, U1.2 (GND), U2.12 (VSSA), U2.18 (VSS), U2.31 (VSS), U2.47 (VSS), U2.63 (VSS), U3.3 (GND), U4.3 (GND), U5.3 (GND), U6.3 (GND)
unnamed: C2.1, U1.4 (BYP)
unnamed: C11.1, U2.30 (VCAP1)
unnamed: D1.1 (K), R4.2
unnamed: D2.1 (K), R5.2
unnamed: D3.1 (K), R6.2
unnamed: D4.1 (K), R11.2
unnamed: D5.1 (K), R12.2
unnamed: D6.1 (K), R13.2
unnamed: D7.1 (K), R14.2
unnamed: D8.1 (K), R15.2
unnamed: D9.1 (K), R3.2
unnamed: R1.1, U2.7 (NRST)
unnamed: R2.1, U2.60 (BOOT0)
unnamed: R7.1, U3.2 (LRSEL)
unnamed: R8.1, U5.2 (LRSEL)
unnamed: R9.1, U4.2 (LRSEL)
unnamed: R10.1, U6.2 (LRSEL)

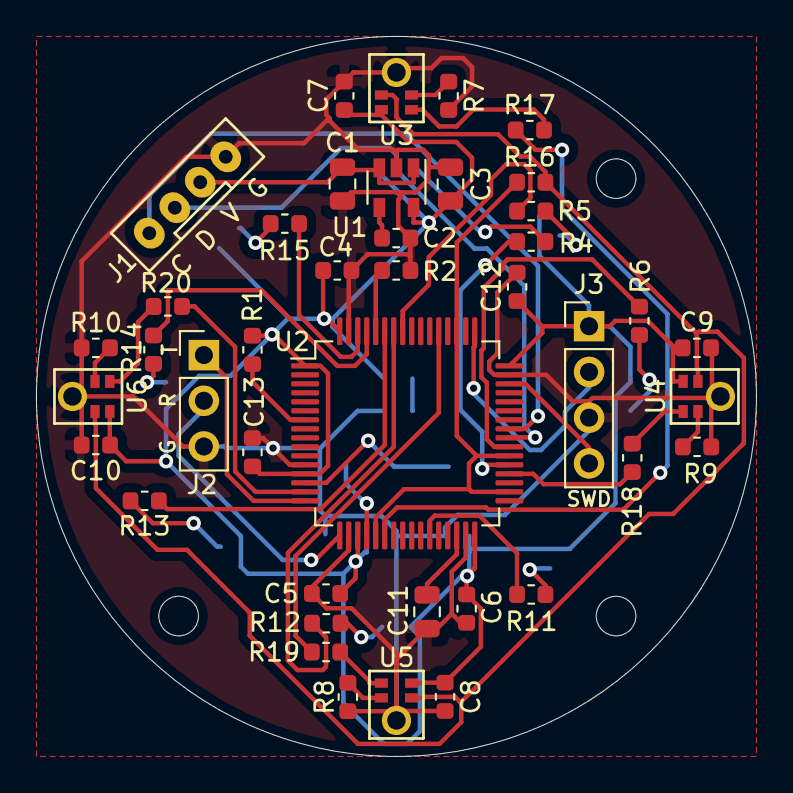
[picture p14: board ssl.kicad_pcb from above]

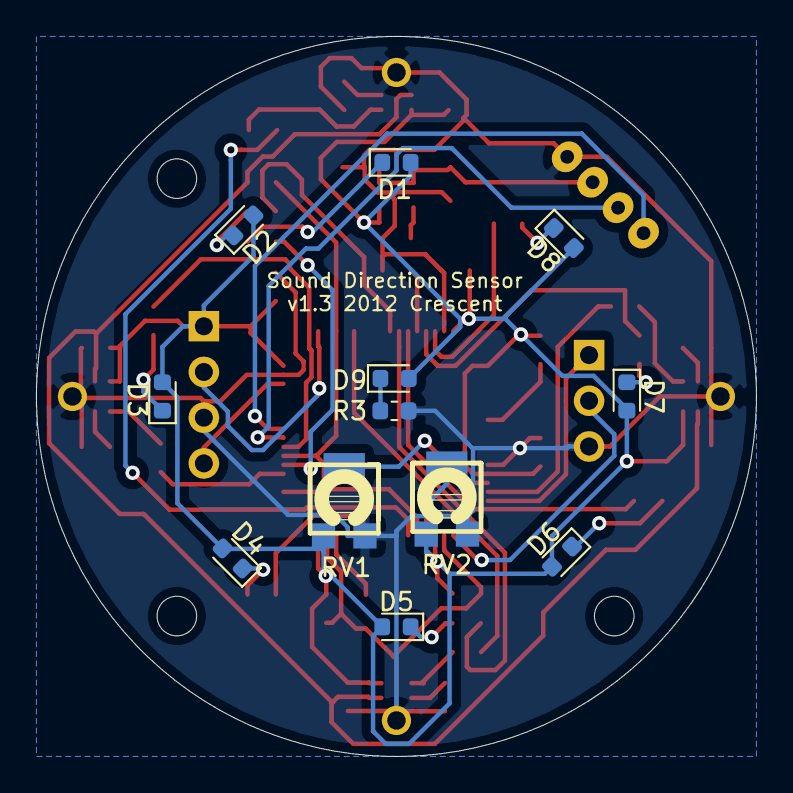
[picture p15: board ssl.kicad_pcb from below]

Board: 2 copper layers, 40.0 x 40.0 mm, 56 parts (12 on the bottom side), 46 nets.

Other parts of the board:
REF1, REF2, REF3: MountingHole_2.2mm_M2

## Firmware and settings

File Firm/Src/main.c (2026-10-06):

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
/* Includes ------------------------------------------------------------------*/
#include "main.h"

/* USER CODE BEGIN Includes */
#include <stdio.h>
#include <stdlib.h>
#include <stdbool.h>
#include <float.h>
#include "pdm_cicfilter.h"
#include "calc_direction.h"
#include "led_control.h"
#include "console.h"
#include "arm_math.h"
#include "arm_const_structs.h"
/* USER CODE END Includes */

/* USER CODE BEGIN PTD */
#define DEV_ADR		0x60
#define DEV_ID		0x43 //Acsii of C
#define I2CRXBUFFERSIZE 8

/* USER CODE END PTD */

ADC_HandleTypeDef hadc1;

I2C_HandleTypeDef hi2c3;
DMA_HandleTypeDef hdma_i2c3_rx;
DMA_HandleTypeDef hdma_i2c3_tx;

SPI_HandleTypeDef hspi1;
SPI_HandleTypeDef hspi2;
SPI_HandleTypeDef hspi3;
SPI_HandleTypeDef hspi4;
DMA_HandleTypeDef hdma_spi1_rx;
DMA_HandleTypeDef hdma_spi2_rx;
DMA_HandleTypeDef hdma_spi3_rx;
DMA_HandleTypeDef hdma_spi4_rx;

TIM_HandleTypeDef htim3;
TIM_HandleTypeDef htim4;

UART_HandleTypeDef huart2;
DMA_HandleTypeDef hdma_usart2_rx;
DMA_HandleTypeDef hdma_usart2_tx;

/* USER CODE BEGIN PV */
float FFT_SampleRate;
float calcDeg;
uint8_t UART2_Data[2];


uint8_t I2CRxBuffer[I2CRXBUFFERSIZE];
uint8_t I2CRegData[8];
uint8_t offset=0;
uint8_t	regOffset;

/* USER CODE END PV */

void SystemClock_Config(void);
static void MX_GPIO_Init(void);
static void MX_DMA_Init(void);
static void MX_SPI1_Init(void);
static void MX_USART2_UART_Init(void);
static void MX_SPI2_Init(void);
static void MX_SPI3_Init(void);
static void MX_SPI4_Init(void);
static void MX_TIM3_Init(void);
static void MX_TIM4_Init(void);
static void MX_ADC1_Init(void);
static void MX_I2C3_Init(void);
/* USER CODE BEGIN 0 */
int _write (int fd, char *ptr, int len)
{
  HAL_UART_Transmit(&huart2, (uint8_t*)ptr, len, 3000);
  return len;
}
void HAL_SPI_RxHalfCpltCallback(SPI_HandleTypeDef *hspi)
{
    if (hspi->Instance == SPI1)
    {
        PDM_DMA_Callback(false);
    }
}

void HAL_SPI_RxCpltCallback(SPI_HandleTypeDef *hspi)
{
    if(hspi->Instance == SPI1)
    {
        PDM_DMA_Callback(true);
    }
}

void HAL_UART_RxCpltCallback(UART_HandleTypeDef *UartHandle)
{

	if(UartHandle->Instance==USART2)
	{
		getConsoleString(UART2_Data);
		HAL_UART_Receive_DMA(&huart2, (uint8_t*)UART2_Data, 1);
	}

}

void HAL_I2C_AddrCallback(I2C_HandleTypeDef *hi2c, uint8_t TransferDirection, uint16_t AddrMatchCode)
{
	uint8_t res;
	if(AddrMatchCode == DEV_ADR)
	{
		if(TransferDirection == I2C_DIRECTION_TRANSMIT)
		{
			res=HAL_I2C_Slave_Seq_Receive_IT(&hi2c3, I2CRxBuffer, 1, I2C_FIRST_FRAME);//I2C_FIRST_FRAME
			if(res!=0)Error_Handler();
			regOffset=0;
		}
		else
		{
			res=HAL_I2C_Slave_Seq_Transmit_IT(&hi2c3, &I2CRegData[offset], sizeof(I2CRegData)-offset, I2C_LAST_FRAME);
			if(res!=0)Error_Handler();
			regOffset=0;
		}
	}
}

void HAL_I2C_SlaveRxCpltCallback(I2C_HandleTypeDef *hi2c)
{
	if(hi2c->Instance==hi2c3.Instance)
	{
		offset=I2CRxBuffer[0];
		if(offset>7)offset=7;

		if(regOffset<I2CRXBUFFERSIZE)
			regOffset++;
		HAL_I2C_Slave_Seq_Receive_IT(&hi2c3, &I2CRxBuffer[regOffset], 1, I2C_FIRST_AND_LAST_FRAME);
		if(offset==4 && regOffset>2)
		{
			uint16_t val16 = (uint16_t)I2CRxBuffer[1]*256+I2CRxBuffer[2];
			setActivityValue((float)val16*0.1f);
		}
	}
}

void HAL_I2C_AbortCpltCallback(I2C_HandleTypeDef *hi2c)
{

}

void HAL_I2C_SlaveTxCpltCallback(I2C_HandleTypeDef *hi2c)
{
	I2CRegData[ENUM_REG_REFRESH] = 0;
}
void HAL_I2C_ListenCpltCallback(I2C_HandleTypeDef *hi2c)
{
	HAL_I2C_EnableListen_IT(hi2c);
}
void HAL_I2C_ErrorCallback(I2C_HandleTypeDef *hi2c)
{
	__HAL_I2C_CLEAR_FLAG(hi2c, I2C_FLAG_AF);
}

/* USER CODE END 0 */

/**
  * @brief  The application entry point.
  * @retval int
  */
int main(void)
{
  /* MCU Configuration--------------------------------------------------------*/

  /* Reset of all peripherals, Initializes the Flash interface and the Systick. */
  HAL_Init();

  /* Configure the system clock */
  SystemClock_Config();

  /* Initialize all configured peripherals */
  MX_GPIO_Init();
  MX_DMA_Init();
  MX_SPI1_Init();
  MX_USART2_UART_Init();
  MX_SPI2_Init();
  MX_SPI3_Init();
  MX_SPI4_Init();
  MX_TIM3_Init();
  MX_TIM4_Init();
  MX_ADC1_Init();
  MX_I2C3_Init();
  /* USER CODE BEGIN 2 */
  	HAL_UART_Receive_DMA(&huart2, (uint8_t*)  UART2_Data, 1);
  	HAL_I2C_EnableListen_IT(&hi2c3);

	printf("\r\nSound Direction Sensor v1.1 (" __DATE__ ")\r\n");

	// Initialize Cic Filter for PDM MEMS MIC
	intiCicFilterAll();

	getAdcValue();
	//Pre Operation
	startPDM();
	HAL_Delay(100);
	disableDMA();
	HAL_Delay(100);

    // FFT init
    float SPI1_BaudRate = (float)SystemCoreClock / 1.0f / 128.0f;//SPI_BAUDRATEPRESCALER_128
    FFT_SampleRate = SPI1_BaudRate / DECIMATION_M;
    printf("Sampling Frq: %.1f kHz\r\n",FFT_SampleRate/1000.0);
    prepareWindow(FFT_SampleRate);
    initLed();

    //Set ID data for i2c reg
    I2CRegData[ENUM_REG_ID]=DEV_ID;

  /* USER CODE END 2 */

  /* Infinite loop */
  /* USER CODE BEGIN WHILE */
	while (1)
	{
		//getAdcValue();

		//Start Sampling
		enableDMA();
		isCalled_PDM_DMA_Callback = false;
		needs_CopyPDMbits = true;

		// Wait for Sampling End
		while (isCalled_PDM_DMA_Callback == false);

		// Get Analog Value from PDM input
		executeCicFilterAll();

		// Calc Sound Source Angle
		calcDeg = calcAngle();

		// Update LED
		updateLedValue(calcDeg);

		// Clear Value for Next Sampling
		clearBufferValue();

		disableDMA();
		HAL_Delay(20);//Must Need to wait over 9msec

    /* USER CODE END WHILE */

    /* USER CODE BEGIN 3 */
	}
  /* USER CODE END 3 */
}

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


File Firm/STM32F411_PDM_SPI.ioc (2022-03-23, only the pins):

Mcu.UserName=STM32F411RETx
PA0-WKUP.Signal=ADCx_IN0
PA1.Signal=SPI4_MOSI
PA13.GPIO_Label=TMS
PA13.Signal=SYS_JTMS-SWDIO
PA14.GPIO_Label=TCK
PA14.Signal=SYS_JTCK-SWCLK
PA2.GPIO_Label=USART_TX
PA2.Signal=USART2_TX
PA3.GPIO_Label=USART_RX
PA3.Signal=USART2_RX
PA4.Signal=ADCx_IN4
PA5.Signal=SPI1_SCK
PA6.Signal=SPI1_MISO
PA8.Signal=I2C3_SCL
PB1.Signal=S_TIM3_CH4
PB13.Signal=SPI4_SCK
PB15.Signal=SPI2_MOSI
PB3.GPIO_Label=SWO
PB3.Signal=SYS_JTDO-SWO
PB5.Signal=S_TIM3_CH2
PB6.Signal=S_TIM4_CH1
PB7.Signal=S_TIM4_CH2
PB8.Signal=S_TIM4_CH3
PB9.Signal=S_TIM4_CH4
PC10.Signal=SPI3_SCK
PC12.Signal=SPI3_MOSI
PC13-ANTI_TAMP.GPIO_Label=B1 [Blue PushButton]
PC13-ANTI_TAMP.Signal=GPXTI13
PC14-OSC32_IN.Signal=RCC_OSC32_IN
PC15-OSC32_OUT.Signal=RCC_OSC32_OUT
PC6.Signal=S_TIM3_CH1
PC7.Signal=SPI2_SCK
PC8.Signal=S_TIM3_CH3
PC9.Signal=I2C3_SDA

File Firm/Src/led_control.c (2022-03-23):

/*
 *  			led_control.c
 *
 *  Copyright (c) 2022
 *  K.Watanabe,Crescent
 *  Released under the MIT license
 *  http://opensource.org/licenses/mit-license.php
 *
 */

/* Include system header files -----------------------------------------------*/
#include "main.h"

/* Include user header files -------------------------------------------------*/
#include "led_control.h"

/* Imported variables --------------------------------------------------------*/
extern TIM_HandleTypeDef htim3;
extern TIM_HandleTypeDef htim4;

uint16_t	ledValue[8]={300};
/* Private function macro ----------------------------------------------------*/
/* Private enum tag ----------------------------------------------------------*/
/* Private variables ---------------------------------------------------------*/
/* Private function prototypes -----------------------------------------------*/
/* Exported functions --------------------------------------------------------*/

void initLed()
{
    ledValue[0] = LEDMAX;
    ledValue[1] = LEDMAX;
    ledValue[2] = LEDMAX;
    ledValue[3] = LEDMAX;
    ledValue[4] = LEDMAX;
    ledValue[5] = LEDMAX;
    ledValue[6] = LEDMAX;
	ledValue[7] = LEDMAX;
    setLedValue();

    HAL_TIM_OC_Start_IT(&htim3, TIM_CHANNEL_1);//MIC1
    HAL_TIM_OC_Start_IT(&htim3, TIM_CHANNEL_2);//MIC1_2
    HAL_TIM_OC_Start_IT(&htim3, TIM_CHANNEL_3);//MIC2
    HAL_TIM_OC_Start_IT(&htim3, TIM_CHANNEL_4);//MIC2_3
    HAL_TIM_OC_Start_IT(&htim4, TIM_CHANNEL_1);//MIC3
    HAL_TIM_OC_Start_IT(&htim4, TIM_CHANNEL_2);//MIC3_4
    HAL_TIM_OC_Start_IT(&htim4, TIM_CHANNEL_3);//MIC4
    HAL_TIM_OC_Start_IT(&htim4, TIM_CHANNEL_4);//MIC4_1

    HAL_Delay(100);

    ledValue[0] = LEDMIN;
    ledValue[1] = LEDMIN;
    ledValue[2] = LEDMIN;
    ledValue[3] = LEDMIN;
    ledValue[4] = LEDMIN;
    ledValue[5] = LEDMIN;
    ledValue[6] = LEDMIN;
	ledValue[7] = LEDMIN;
    setLedValue();
}


void setLedValue()
{
    //Check Overflow
	if(ledValue[0]>LEDMIN)
    	ledValue[0]=LEDMIN;
    if(ledValue[1]>LEDMIN)
    	ledValue[1]=LEDMIN;
    if(ledValue[2]>LEDMIN)
    	ledValue[2]=LEDMIN;
    if(ledValue[3]>LEDMIN)
    	ledValue[3]=LEDMIN;
    if(ledValue[4]>LEDMIN)
    	ledValue[4]=LEDMIN;
    if(ledValue[5]>LEDMIN)
    	ledValue[5]=LEDMIN;
    if(ledValue[6]>LEDMIN)
    	ledValue[6]=LEDMIN;
    if(ledValue[7]>LEDMIN)
    	ledValue[7]=LEDMIN;

    //Set Pwm Value
	__HAL_TIM_SET_COMPARE( &htim3, TIM_CHANNEL_1, ledValue[0]);//MIC1
    __HAL_TIM_SET_COMPARE( &htim3, TIM_CHANNEL_2, ledValue[1]);//MIC1_2
    __HAL_TIM_SET_COMPARE( &htim3, TIM_CHANNEL_3, ledValue[2]);//MIC2
    __HAL_TIM_SET_COMPARE( &htim3, TIM_CHANNEL_4, ledValue[3]);//MIC2_3
    __HAL_TIM_SET_COMPARE( &htim4, TIM_CHANNEL_1, ledValue[4]);//MIC3
    __HAL_TIM_SET_COMPARE( &htim4, TIM_CHANNEL_2, ledValue[5]);//MIC3_4
    __HAL_TIM_SET_COMPARE( &htim4, TIM_CHANNEL_3, ledValue[6]);//MIC4
    __HAL_TIM_SET_COMPARE( &htim4, TIM_CHANNEL_4, ledValue[7]);//MIC4_1

}


void updateLedValue(float deg)
{
	if( 0 < deg && deg < 22.5 )
	{
	    ledValue[0] = LEDMAX;
	    ledValue[1]+= LEDGRAD;
	    ledValue[2]+= LEDGRAD;
	    ledValue[3]+= LEDGRAD;
	    ledValue[4]+= LEDGRAD;
	    ledValue[5]+= LEDGRAD;
	    ledValue[6]+= LEDGRAD;
		ledValue[7]+= LEDGRAD;
	}
	else if( 22.5 < deg && deg < 45+22.5 )
	{
	    ledValue[0]+= LEDGRAD;
	    ledValue[1] = LEDMAX;
	    ledValue[2]+= LEDGRAD;
	    ledValue[3]+= LEDGRAD;
	    ledValue[4]+= LEDGRAD;
	    ledValue[5]+= LEDGRAD;
	    ledValue[6]+= LEDGRAD;
		ledValue[7]+= LEDGRAD;
	}
	else if( 45+22.5 < deg && deg < 90+22.5 )
	{

	    ledValue[0]+= LEDGRAD;
	    ledValue[1]+= LEDGRAD;
	    ledValue[2] = LEDMAX;
	    ledValue[3]+= LEDGRAD;
	    ledValue[4]+= LEDGRAD;
	    ledValue[5]+= LEDGRAD;
	    ledValue[6]+= LEDGRAD;
		ledValue[7]+= LEDGRAD;

	}
	else if( 90+22.5 < deg && deg < 135+22.5 )
	{
	    ledValue[0]+= LEDGRAD;
	    ledValue[1]+= LEDGRAD;
	    ledValue[2]+= LEDGRAD;
	    ledValue[3] = LEDMAX;
	    ledValue[4]+= LEDGRAD;
	    ledValue[5]+= LEDGRAD;
	    ledValue[6]+= LEDGRAD;
		ledValue[7]+= LEDGRAD;

	}
	else if( 135+22.5 < deg && deg < 180+22.5 )
	{

	    ledValue[0]+= LEDGRAD;
	    ledValue[1]+= LEDGRAD;
	    ledValue[2]+= LEDGRAD;
	    ledValue[3]+= LEDGRAD;
	    ledValue[4] = LEDMAX;
	    ledValue[5]+= LEDGRAD;
	    ledValue[6]+= LEDGRAD;
		ledValue[7]+= LEDGRAD;

	}
	else if( 180+22.5 < deg && deg < 225+22.5 )
	{

	    ledValue[0]+= LEDGRAD;
	    ledValue[1]+= LEDGRAD;
	    ledValue[2]+= LEDGRAD;
	    ledValue[3]+= LEDGRAD;
	    ledValue[4]+= LEDGRAD;
	    ledValue[5] = LEDMAX;
	    ledValue[6]+= LEDGRAD;
		ledValue[7]+= LEDGRAD;

	}
	else if( 225+22.5 < deg && deg < 270+22.5 )
	{

	    ledValue[0]+= LEDGRAD;
	    ledValue[1]+= LEDGRAD;
	    ledValue[2]+= LEDGRAD;
	    ledValue[3]+= LEDGRAD;
	    ledValue[4]+= LEDGRAD;
	    ledValue[5]+= LEDGRAD;
	    ledValue[6] = LEDMAX;
		ledValue[7]+= LEDGRAD;

	}
	else if( 270+22.5 < deg && deg < 315+22.5 )
	{
	    ledValue[0]+= LEDGRAD;
	    ledValue[1]+= LEDGRAD;
	    ledValue[2]+= LEDGRAD;
	    ledValue[3]+= LEDGRAD;
	    ledValue[4]+= LEDGRAD;
	    ledValue[5]+= LEDGRAD;
	    ledValue[6]+= LEDGRAD;
		ledValue[7] = LEDMAX;
	}
	else if( deg > 315+22.5 )
	{
	    ledValue[0] = LEDMAX;
	    ledValue[1]+= LEDGRAD;
	    ledValue[2]+= LEDGRAD;
	    ledValue[3]+= LEDGRAD;
	    ledValue[4]+= LEDGRAD;
	    ledValue[5]+= LEDGRAD;
	    ledValue[6]+= LEDGRAD;
		ledValue[7]+= LEDGRAD;

	}
	else
	{
	    ledValue[0]+= LEDGRAD;
	    ledValue[1]+= LEDGRAD;
	    ledValue[2]+= LEDGRAD;
	    ledValue[3]+= LEDGRAD;
	    ledValue[4]+= LEDGRAD;
	    ledValue[5]+= LEDGRAD;
	    ledValue[6]+= LEDGRAD;
		ledValue[7]+= LEDGRAD;
	}

    setLedValue();
}

/* Private functions ---------------------------------------------------------*/

/***************************************************************END OF FILE****/

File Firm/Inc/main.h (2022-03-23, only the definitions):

#define B1_Pin GPIO_PIN_13
#define B1_GPIO_Port GPIOC
#define USART_TX_Pin GPIO_PIN_2
#define USART_TX_GPIO_Port GPIOA
#define USART_RX_Pin GPIO_PIN_3
#define USART_RX_GPIO_Port GPIOA
#define TMS_Pin GPIO_PIN_13
#define TMS_GPIO_Port GPIOA
#define TCK_Pin GPIO_PIN_14
#define TCK_GPIO_Port GPIOA
#define SWO_Pin GPIO_PIN_3
#define SWO_GPIO_Port GPIOB

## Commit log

2022-03-21 Add PCB Data
    [BOM.csv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]
2022-04-22 Add sample code
2026-10-06 Improved algorithms and filters to reduce false detections

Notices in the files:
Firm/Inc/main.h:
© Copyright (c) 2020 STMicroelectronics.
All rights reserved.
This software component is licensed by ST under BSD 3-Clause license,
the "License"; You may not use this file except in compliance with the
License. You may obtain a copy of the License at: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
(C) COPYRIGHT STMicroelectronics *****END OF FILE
